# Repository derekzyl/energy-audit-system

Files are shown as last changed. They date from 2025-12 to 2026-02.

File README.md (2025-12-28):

# IoT Enabled  Energy Audit System

A comprehensive, offline energy monitoring solution for real-time power consumption analysis, waste detection, and intelligent energy auditing across multiple wired and wireless loads.

## 🎯 Overview

This system provides a complete energy audit solution without requiring cloud connectivity, internet access, or complex authentication. It consists of a main auditor ESP32 that monitors wired loads and receives data from portable wireless nodes, all accessible through a modern web dashboard.

### Key Features

- **Real-time Energy Monitoring**: Monitor voltage, current, power, energy consumption, and power factor
- **Multi-Device Support**: Simultaneously monitor 2 wired loads (PZEM-004T) and unlimited wireless nodes
- **Intelligent Waste Detection**: Automatic identification of standby waste, usage anomalies, and efficiency issues
- **Wireless Connectivity**: ESP-NOW protocol for low-power, reliable communication without routers
- **Web Dashboard**: Modern, responsive web interface with real-time charts and alerts
- **Portable Nodes**: Battery-powered wireless sensors for flexible deployment
- **Dynamic Device Management**: Automatically discover wireless nodes and manage device names through the web interface
- **Offline Operation**: Complete system works without internet or cloud services
- **Historical Data**: Track power consumption trends over time

## 🏗️ System Architecture

```
┌─────────────────────────┐         ESP-NOW Protocol
│  Wireless Audit Node    │ ────────────────────────▶
│  (SCT-013 Clamp Sensor) │                            │
│  Battery Powered        │                            │
└─────────────────────────┘                            │
                                                       │
                                                       ▼
┌─────────────────────────┐                    ┌─────────────────────┐
│  PZEM-004T Sensor 1     │ ──── UART ────────▶ │                     │
│  (Wired Load 1)         │                    │  Main Auditor ESP32 │
└─────────────────────────┘                    │                     │
                                                │  • WiFi Access Point│
┌─────────────────────────┐                    │  • Web Server      │
│  PZEM-004T Sensor 2     │ ──── UART ────────▶ │  • ESP-NOW Receiver│
│  (Wired Load 2)         │                    │  • Data Storage    │
└─────────────────────────┘                    │  • Waste Detection │
                                                └─────────────────────┘
                                                         │
                                                         ▼
                                                ┌─────────────────────┐
                                                │  Web Dashboard     │
                                                │  (192.168.4.1)     │
                                                │  • Real-time Data  │
                                                │  • Charts & Graphs │
                                                │  • Device Management│
                                                │  • Waste Alerts    │
                                                └─────────────────────┘
```

## 📋 Components

### Main Auditor ESP32
- Acts as WiFi Access Point (SSID: `EnergyAudit-AP`)
- Hosts web dashboard and REST API
- Receives data from wireless nodes via ESP-NOW
- Monitors 2 wired loads via PZEM-004T sensors
- Performs waste detection analysis
- Stores historical data in memory

### Wireless Audit Nodes
- Battery-powered portable sensors
- SCT-013 current clamp sensor
- ESP-NOW transmitter
- Automatic calibration
- Low-power operation

## 🚀 Quick Start

### Prerequisites

- PlatformIO IDE or PlatformIO Core
- ESP32 Development Boards
- Hardware components (see [BOM.md](BOM.md))

### Installation

1. **Clone the repository**
   ```bash
   git clone <repository-url>
   cd energy-audit-system
   ```

2. **Upload Main Auditor Firmware**
   ```bash
   cd firmware
   pio run -t upload
   pio device monitor  # Note the MAC address
   ```

3. **Configure Wireless Node**
   - Update `wireless-audit-device/include/config.h` with main auditor's MAC address
   - Set node ID and sensor parameters

4. **Upload Wireless Node Firmware**
   ```bash
   cd wireless-audit-device
   pio run -t upload
   ```

5. **Access Dashboard**
   - Connect to WiFi: `EnergyAudit-AP` (password: `audit12345`)
   - Open browser: `http://192.168.4.1`

## 📖 Documentation

- **[BOM.md](BOM.md)** - Complete Bill of Materials with part numbers and suppliers
- **[ENERGY_AUDIT_EXPLAINED.md](ENERGY_AUDIT_EXPLAINED.md)** - Detailed explanation of energy audit methodology
- **[SETUP.md](SETUP.md)** - Hardware setup and configuration guide
- **[PROJECT_STRUCTURE.md](PROJECT_STRUCTURE.md)** - Code structure and architecture

## 🔧 Configuration

### Main Auditor
Edit `firmware/include/config.h`:
- WiFi AP credentials
- PZEM sensor pin assignments
- ESP-NOW channel
- Waste detection thresholds

### Wireless Node
Edit `wireless-audit-device/include/config.h`:
- Node ID and name
- Master MAC address
- Sensor calibration values
- Transmission interval

## 💻 API Endpoints

### Device Management
- `GET /api/devices` - List all devices with current readings
- `GET /api/device/:id` - Get specific device details
- `GET /api/devices/:id` - Get device history data
- `POST /api/device/:id/rename` - Rename a device (parameter: `name`)
- `POST /api/device/:id/delete` - Remove a wireless device (wired devices cannot be deleted)

### Dashboard
- `GET /` - Web dashboard interface

## 🎨 Dashboard Features

- **Real-time Monitoring**: Live updates every 2 seconds
- **Device Cards**: Individual cards for each monitored device
- **Power Charts**: Historical power consumption graphs
- **Waste Alerts**: Visual indicators for energy waste
- **Device Management**: 
  - Automatic discovery of wireless nodes when they connect
  - Rename devices with custom names through the web interface
  - Delete wireless devices (wired devices are permanent)
  - Custom names persist during device operation
- **Mobile Responsive**: Works on smartphones and tablets
- **Status Indicators**: Active/inactive device status

## 🔍 Waste Detection

The system automatically detects three types of energy waste:

1. **Standby Waste**: Low current (<0.2A) but still consuming power (>5W)
2. **Usage Anomaly**: Device running continuously 24/7
3. **Efficiency Issue**: Low power factor (<0.7) indicating poor efficiency

## 📊 Data Collection

- **Sampling Rate**: 
  - Wired loads: Every 2 seconds
  - Wireless nodes: Every 5 seconds
- **History Storage**: Last 1000 readings per device (in RAM)
- **Statistics**: Total energy, average power, maximum power, uptime

## 🔌 Hardware Connections

### Main Auditor - PZEM-004T
- **PZEM 1**: RX→GPIO16, TX→GPIO17
- **PZEM 2**: RX→GPIO18, TX→GPIO19
- Connect PZEM in series with loads to measure

### Wireless Node - SCT-013
- Clamp sensor around wire
- Burden resistor (33-62Ω) to GPIO34
- Battery power via 3.3V regulator

See [SETUP.md](SETUP.md) for detailed wiring diagrams.

## 🛠️ Development

### Project Structure
```
energy-audit-system/
├── firmware/              # Main auditor firmware
│   ├── include/          # Header files
│   └── src/              # Source files
├── wireless-audit-device/ # Wireless node firmware
│   ├── include/
│   └── src/
└── docs/                 # Documentation
```

### Building
```bash
# Main auditor
cd firmware
pio run

# Wireless node
cd wireless-audit-device
pio run
```

### Dependencies
- ArduinoJson 6.21.3
- ESPAsyncWebServer 1.2.3
- AsyncTCP 1.1.1

## 🐛 Troubleshooting

### Common Issues

**WiFi AP not starting**
- Check serial monitor for errors
- Verify ESP32 has sufficient power
- Try changing AP channel

**PZEM not reading**
- Verify wiring (RX/TX may be swapped)
- Check PZEM address matches config
- Ensure PZEM is powered (LED should blink)

**ESP-NOW not receiving**
- Verify MAC addresses are correct
- Check both devices on same channel
- Ensure devices are powered on

**Wireless node inaccurate readings**
- Recalibrate sensor (power off, remove load, power on)
- Verify burden resistor value
- Check SCT-013 clamp is secure

See [SETUP.md](SETUP.md) for detailed troubleshooting.

## 📈 Future Enhancements

- [ ] Deep sleep mode for wireless nodes
- [ ] Voltage sensor for wireless nodes
- [ ] SPIFFS/SD card data logging
- [ ] Energy cost calculations
- [ ] CSV data export
- [ ] Mobile app interface
- [ ] Multi-language support
- [ ] Advanced analytics and reporting

## 📝 License

This project is provided as-is for educational and development purposes.

## 🤝 Contributing

Contributions are welcome! Please feel free to submit pull requests or open issues for bugs and feature requests.

## 📧 Support

For questions, issues, or contributions, please open an issue on the repository.

---

**Version**: 1.0.0  
**Last Updated**: 2025  
**Platform**: ESP32 (Arduino Framework)

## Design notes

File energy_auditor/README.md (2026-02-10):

# energy_auditor

A new Flutter project.

## Getting Started

This project is a starting point for a Flutter application.

A few resources to get you started if this is your first Flutter project:

- [Lab: Write your first Flutter app](https://docs.flutter.dev/get-started/codelab)
- [Cookbook: Useful Flutter samples](https://docs.flutter.dev/cookbook)

For help getting started with Flutter development, view the
[online documentation](https://docs.flutter.dev/), which offers tutorials,
samples, guidance on mobile development, and a full API reference.

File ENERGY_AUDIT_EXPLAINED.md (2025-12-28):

# Energy Audit System - How It Works

A comprehensive explanation of the energy audit methodology, measurement techniques, and intelligent waste detection algorithms.

## 📊 Overview

This system performs real-time energy auditing by measuring electrical parameters (voltage, current, power) and analyzing consumption patterns to identify energy waste and optimization opportunities.

## 🔌 Measurement Methods

### 1. Wired Loads (PZEM-004T)

**How It Works:**
- PZEM-004T is an inline energy meter that connects in series with the load
- Uses a current transformer (CT) to measure current non-invasively
- Directly measures voltage, current, power, energy, frequency, and power factor
- Communicates via Modbus RTU protocol over UART

**Advantages:**
- High accuracy (±1%)
- Direct voltage measurement (no assumptions)
- Real power factor measurement
- Energy accumulation (kWh)
- Frequency measurement

**Limitations:**
- Requires physical connection to load
- Not portable
- Installation requires electrical work

**Measurement Parameters:**
```
Voltage (V):     80-260V AC (direct measurement)
Current (A):     0-100A (via CT)
Power (W):       0-22.9kW (calculated: V × I × PF)
Energy (kWh):    Accumulated over time
Frequency (Hz):  50-60Hz
Power Factor:    0.0-1.0 (cosine of phase angle)
```

### 2. Wireless Nodes (SCT-013)

**How It Works:**
- SCT-013 is a non-invasive current transformer (clamp sensor)
- Clamps around a single wire (not the entire cable)
- Outputs current proportional to line current (100A:50mA ratio)
- Burden resistor converts current to voltage for ADC reading
- ESP32 ADC samples the waveform and calculates RMS current

**Advantages:**
- Non-invasive installation (no wiring changes)
- Portable and battery-powered
- Easy to move between loads
- Safe (no direct electrical connection)

**Limitations:**
- Only measures current (voltage assumed)
- Power factor estimated (not measured)
- Less accurate than PZEM (±3% vs ±1%)
- Requires calibration

**Measurement Process:**

```
1. Clamp SCT-013 around wire
   ↓
2. AC current induces current in sensor (proportional)
   ↓
3. Burden resistor converts to voltage: V = I_sensor × R_burden
   ↓
4. ESP32 ADC samples waveform at 10kHz
   ↓
5. Calculate RMS current: I_RMS = √(Σ(I²)/N)
   ↓
6. Estimate power: P = I_RMS × V_assumed × PF_estimated
```

**Power Calculation:**
```
Power (W) = Current (A) × Voltage (V) × Power Factor

Where:
- Current: Measured RMS value
- Voltage: Assumed 230V (configurable)
- Power Factor: Estimated based on load characteristics
  - Small loads (<0.5A): PF ≈ 0.75
  - Medium loads (0.5-2A): PF ≈ 0.85
  - Large loads (>2A): PF ≈ 0.90
```

## 🧮 Electrical Calculations

### RMS Current Calculation

For AC circuits, we need Root Mean Square (RMS) current, not peak current:

```
I_RMS = √(1/T × ∫[i(t)]² dt)

Where:
- T = period (20ms for 50Hz)
- i(t) = instantaneous current

In practice (discrete sampling):
I_RMS = √(Σ(I_sample²) / N)

Where N = number of samples
```

### Power Calculations

**Real Power (W):**
```
P = V_RMS × I_RMS × cos(φ)

Where:
- V_RMS = RMS voltage
- I_RMS = RMS current  
- φ = phase angle between voltage and current
- cos(φ) = power factor
```

**Apparent Power (VA):**
```
S = V_RMS × I_RMS
```

**Reactive Power (VAR):**
```
Q = V_RMS × I_RMS × sin(φ)
```

**Power Factor:**
```
PF = P / S = cos(φ)
```

### Energy Calculation

Energy is power integrated over time:

```
E = ∫ P(t) dt

In discrete form:
E = Σ(P_i × Δt_i)

Where:
- P_i = power at sample i
- Δt_i = time interval between samples
```

The system accumulates energy in kWh:
```
E_kWh = E_Joules / 3,600,000
```

## 🔍 Waste Detection Algorithms

### 1. Standby Waste Detection

**Definition:** Device consuming power while in standby/low-power mode.

**Detection Logic:**
```cpp
if (current < 0.2A && power > 5W) {
    standbyWaste = true;
}
```

**Why This Works:**
- Low current (<0.2A) suggests device is "off" or in standby
- But power >5W indicates it's still consuming energy
- This is wasteful - device should consume <1W in standby

**Examples:**
- TV on standby: 0.15A @ 230V = 34.5W (wasteful!)
- Phone charger (no phone): 0.05A @ 230V = 11.5W (wasteful!)
- LED bulb: 0.08A @ 230V = 18.4W (normal, not waste)

**Thresholds:**
- Current threshold: 0.2A (configurable)
- Power threshold: 5W (configurable)

### 2. Usage Anomaly Detection

**Definition:** Device running continuously 24/7, indicating potential waste.

**Detection Logic:**
```cpp
// Analyze last 100 readings
int alwaysOnCount = 0;
for (int i = 0; i < 100; i++) {
    if (history[i].power > 1.0W) {
        alwaysOnCount++;
    }
}

// If 95%+ of readings show consumption
if (alwaysOnCount >= 95) {
    usageAnomaly = true;
}
```

**Why This Works:**
- Most devices should have periods of zero/low consumption
- Continuous consumption suggests:
  - Device left on unnecessarily
  - Faulty device (always drawing power)
  - Critical system (acceptable, but flagged for review)

**Examples:**
- Refrigerator: Always on (normal, but flagged)
- Server/Computer: Always on (may be unnecessary)
- Security system: Always on (normal)
- Light left on: Always on (wasteful!)

**Analysis Window:**
- Checks last 100 readings
- At 5-second intervals = ~8.3 minutes of data
- Can be extended for longer-term analysis

### 3. Efficiency Issue Detection

**Definition:** Low power factor indicates poor electrical efficiency.

**Detection Logic:**
```cpp
if (powerFactor > 0.0 && powerFactor < 0.7) {
    efficiencyIssue = true;
}
```

**Why This Works:**
- Power factor < 1.0 means device draws more current than needed
- Low PF (<0.7) indicates:
  - Reactive loads (motors, transformers)
  - Poor power quality
  - Inefficient power supply
  - Need for power factor correction

**Power Factor Ranges:**
- **Excellent**: 0.95 - 1.0 (resistive loads, modern electronics)
- **Good**: 0.85 - 0.95 (most appliances)
- **Fair**: 0.70 - 0.85 (motors, some electronics)
- **Poor**: < 0.70 (inductive loads, old equipment)

**Examples:**
- LED bulb: PF ≈ 0.95 (good)
- Laptop: PF ≈ 0.90 (good)
- Refrigerator: PF ≈ 0.65 (poor, needs correction)
- Old fluorescent light: PF ≈ 0.50 (very poor)

**Impact:**
- Low PF increases current draw
- Higher current = more losses in wiring
- Utility may charge for reactive power
- Reduces overall system efficiency

## 📈 Data Analysis and Statistics

### Real-time Metrics

**Current Reading:**
- Latest voltage, current, power, energy, frequency, PF
- Timestamp of measurement
- Device status (active/inactive)

**Historical Data:**
- Circular buffer of last 1000 readings
- Stored in RAM (fast access)
- Used for trend analysis

### Calculated Statistics

**Total Energy:**
```
E_total = Σ(P_i × Δt_i) / 3,600,000 kWh
```

**Average Power:**
```
P_avg = (Σ P_i) / N
```

**Maximum Power:**
```
P_max = max(P_i)
```

**Uptime:**
```
Uptime = (last_seen - first_seen) seconds
```

## 🔄 System Workflow

### Main Auditor Operation

```
1. Initialize WiFi AP
   ↓
2. Start web server
   ↓
3. Initialize ESP-NOW receiver
   ↓
4. Initialize PZEM sensors
   ↓
5. Main Loop:
   ├─ Read PZEM sensors (every 2s)
   ├─ Receive ESP-NOW packets (asynchronous)
   ├─ Update device data
   ├─ Run waste detection (every 60s)
   └─ Serve web requests
```

### Wireless Node Operation

```
1. Initialize WiFi (for ESP-NOW)
   ↓
2. Calibrate current sensor (find DC offset)
   ↓
3. Initialize ESP-NOW transmitter
   ↓
4. Main Loop:
   ├─ Sample current waveform (100 samples)
   ├─ Calculate RMS current
   ├─ Estimate power
   ├─ Create JSON packet
   └─ Transmit via ESP-NOW (every 5s)
```

## 🎯 Accuracy and Calibration

### PZEM-004T Accuracy
- **Voltage**: ±1% (factory calibrated)
- **Current**: ±1% (via CT)
- **Power**: ±1% (calculated)
- **Energy**: ±1% (accumulated)

### SCT-013 Accuracy
- **Current**: ±3% (after calibration)
- **Power**: ±5-10% (due to assumed voltage and PF)

### Calibration Process

**Wireless Node:**
1. Power on with no load
2. System measures DC offset
3. Offset subtracted from all readings
4. Burden resistor value verified
5. Current ratio verified

**PZEM:**
- Factory calibrated
- Verify with known load if needed

## 📊 Data Interpretation

### Understanding Readings

**Normal Operation:**
- Current varies with load
- Power factor 0.85-0.95
- Periodic zero consumption

**Standby Mode:**
- Current < 0.2A
- Power < 5W (ideal) or > 5W (wasteful)
- Power factor may be low

**Fault Conditions:**
- Sudden power spikes
- Erratic readings
- Zero readings (connection issue)

### Energy Waste Indicators

**High Priority:**
- Standby waste detected
- Usage anomaly (24/7 operation)
- Low power factor (<0.7)

**Medium Priority:**
- Continuous low consumption
- High idle power

**Low Priority:**
- Occasional waste
- Acceptable 24/7 operation (refrigerator, etc.)

## 🔧 Optimization Recommendations

Based on waste detection, the system can suggest:

1. **Standby Waste**: Unplug device or use smart switch
2. **Usage Anomaly**: Review if device needs to run 24/7
3. **Efficiency Issue**: Consider power factor correction capacitor

## 📚 Technical References

### Standards
- **IEC 61000-4-30**: Power quality measurement
- **IEEE 1459**: Power definitions
- **IEC 62053**: Energy metering

### Formulas
- **RMS Calculation**: I_RMS = √(1/T × ∫i²dt)
- **Power Factor**: PF = P / (V × I)
- **Energy**: E = ∫P dt

### Typical Power Factors
- Resistive loads: 1.0
- LED lights: 0.95-0.99
- Computers: 0.85-0.95
- Motors: 0.60-0.85
- Fluorescent lights: 0.50-0.90

---

**Last Updated**: 2025  
**Version**: 1.0.0

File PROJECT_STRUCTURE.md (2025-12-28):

# Project Structure

## Directory Layout

```
energy-audit-system/
├── firmware/                    # Main Auditor ESP32 Firmware
│   ├── include/
│   │   ├── config.h            # Configuration (WiFi, PZEM pins, thresholds)
│   │   ├── device_data.h       # Data structures for devices and readings
│   │   ├── pzem_sensor.h       # PZEM-004T sensor interface
│   │   └── waste_detector.h    # Waste detection algorithms
│   ├── src/
│   │   ├── main.cpp            # Main firmware (WiFi AP, Web server, ESP-NOW)
│   │   ├── pzem_sensor.cpp     # PZEM sensor implementation
│   │   └── waste_detector.cpp  # Waste detection implementation
│   ├── platformio.ini          # PlatformIO configuration
│   └── ...
│
├── wireless-audit-device/       # Wireless Node Firmware
│   ├── include/
│   │   ├── config.h            # Node configuration (sensor pins, ESP-NOW)
│   │   └── current_sensor.h    # SCT-013 current sensor interface
│   ├── src/
│   │   ├── main.cpp            # Main node firmware (ESP-NOW transmitter)
│   │   └── current_sensor.cpp  # Current sensor implementation
│   ├── platformio.ini          # PlatformIO configuration
│   └── ...
│
├── readme.md                    # Project overview and architecture
├── SETUP.md                     # Hardware setup and configuration guide
└── PROJECT_STRUCTURE.md         # This file
```

## Key Components

### Main Auditor (`firmware/`)

**Core Features:**
- WiFi Access Point mode (SSID: `EnergyAudit-AP`)
- Web server with real-time dashboard
- ESP-NOW receiver for wireless nodes
- 2x PZEM-004T sensor interfaces (wired loads)
- REST API endpoints
- Waste detection algorithms
- Data storage and history tracking

**Main Files:**
- `main.cpp`: Orchestrates WiFi AP, web server, ESP-NOW, and PZEM sensors
- `pzem_sensor.cpp`: Modbus RTU communication with PZEM-004T
- `waste_detector.cpp`: Analyzes devices for standby waste, anomalies, efficiency issues

**API Endpoints:**
- `GET /` - Web dashboard (HTML)
- `GET /api/devices` - List all devices with current readings
- `GET /api/device/:id` - Get specific device details
- `GET /api/devices/:id` - Get device history data

### Wireless Node (`wireless-audit-device/`)

**Core Features:**
- SCT-013 current clamp sensor reading
- RMS current calculation
- Power estimation (Current × Voltage × PF)
- ESP-NOW transmitter to main auditor
- Battery-powered operation
- Auto-calibration on startup

**Main Files:**
- `main.cpp`: ESP-NOW transmission, sensor reading loop
- `current_sensor.cpp`: ADC sampling, RMS calculation, power factor estimation

## Data Flow

```
Wireless Node                    Main Auditor                    Web Dashboard
     │                                │                                │
     │ 1. Sample SCT-013              │                                │
     │ 2. Calculate RMS Current        │                                │
     │ 3. Estimate Power               │                                │
     │                                │                                │
     │ ──── ESP-NOW ─────────────────▶│                                │
     │                                │ 4. Parse JSON packet            │
     │                                │ 5. Update device data           │
     │                                │ 6. Run waste detection          │
     │                                │                                │
     │                                │ ──── HTTP Request ────────────▶│
     │                                │                                │ 7. Display data
     │                                │                                │ 8. Show alerts
     │                                │                                │ 9. Update charts
     │                                │                                │
     │                                │                                │
PZEM Sensors ──── UART ──────────────▶│                                │
     │                                │ Read voltage, current, power    │
     │                                │ Update device data              │
     │                                │                                │
```

## Configuration Files

### `firmware/include/config.h`
- WiFi AP credentials
- PZEM pin assignments
- ESP-NOW channel
- Waste detection thresholds
- Device IDs

### `wireless-audit-device/include/config.h`
- Node ID and name
- SCT-013 sensor configuration
- Burden resistor value
- ESP-NOW master MAC address
- Transmission interval

## Waste Detection

The system detects three types of energy waste:

1. **Standby Waste**: Current < 0.2A but power > 5W
   - Indicates device consuming power in standby mode

2. **Usage Anomaly**: Device running 24/7
   - Detected by analyzing history (95%+ of readings show consumption)

3. **Efficiency Issue**: Power factor < 0.7
   - Low power factor indicates poor efficiency

## Data Structures

### `DeviceReading`
- voltage, current, power, energy, frequency, powerFactor
- timestamp

### `DeviceInfo`
- Device identification (id, name, type)
- Current reading
- History buffer (circular)
- Statistics (total energy, avg/max power)
- Waste detection flags
- Status (active/inactive, last seen)

## Dependencies

### Main Auditor
- `ArduinoJson` - JSON parsing/generation
- `ESPAsyncWebServer` - Async web server
- `AsyncTCP` - TCP library for async server

### Wireless Node
- `ArduinoJson` - JSON packet creation

## Build & Upload

### Main Auditor
```bash
cd firmware
pio run -t upload
pio device monitor  # View serial output
```

### Wireless Node
```bash
cd wireless-audit-device
pio run -t upload
pio device monitor  # View serial output
```

## Testing

1. Upload main auditor firmware
2. Note MAC address from serial monitor
3. Update wireless node config with MAC address
4. Upload wireless node firmware
5. Connect to WiFi AP: `EnergyAudit-AP`
6. Open browser: `http://192.168.4.1`
7. Verify devices appear in dashboard

## Notes

- PZEM sensors use Modbus RTU over UART (9600 baud)
- ESP-NOW uses channel 1 by default
- Web dashboard auto-refreshes every 2 seconds
- History is stored in RAM (circular buffer, max 1000 entries)
- Wireless node transmits every 5 seconds
- PZEM sensors are read every 2 seconds

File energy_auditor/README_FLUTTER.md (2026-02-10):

# Energy Auditor Mobile App

## Overview
Flutter application for monitoring energy usage and receiving waste alerts.

## Features
-   Real-time Dashboard (Watts, Amps, Temp, Lux).
-   Active Waste Alerts (Overcooling, Lights on, etc.).
-   Historical Analytics Charts.
-   Device Configuration.

## Setup
1.  Navigate to `energy_auditor/`.
2.  Get dependencies: `flutter pub get`.
3.  Run:
    ```bash
    flutter run
    ```

## Configuration
-   On first launch, go to **Settings** icon.
-   Enter Backend URL: `http://YOUR_PC_IP:8000`.
-   Enter Device ID: `ESP32_...` (matches firmware ID).

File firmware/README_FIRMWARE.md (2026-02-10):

# ESP32 Firmware for Energy Audit System

## Overview
This firmware runs on the ESP32 and performs:
-   RMS Current reading from 2x ACS712 sensors.
-   Environmental sensing (DHT22, LDR).
-   Dual WiFi Mode (AP for config, Station for normal op).
-   Local Web Dashboard.
-   JSON data push to FastAPI Backend.

## Hardware Config
-   **ACS712 1**: GPIO 34
-   **ACS712 2**: GPIO 35
-   **LDR**: GPIO 32
-   **DHT22**: GPIO 4

## Setup
1.  Open `firmware/` in VS Code with PlatformIO.
2.  Connect ESP32 via USB.
3.  Click **Upload**.
4.  Monitor Serial Output (115200 baud).

## usage
-   **First Run**: Connect to WiFi AP `EnergyMonitor_Setup` (Pass: `energy123`).
-   Go to `http://192.168.4.1/config`.
-   Enter your Backend URL (e.g., `http://YOUR_PC_IP:8000`).
-   Save & Reboot.

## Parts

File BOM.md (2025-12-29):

# Bill of Materials (BOM)

Complete parts list for the IoT Enabled  Energy Audit System.

## Main Auditor ESP32

| Part | Quantity | Description | Part Number/Supplier |
|---|---|---|---|
| ESP32 Development Board | 1 | ESP32-WROOM-32 or ESP32-DevKitC | ESP32-DevKitC-32 |
| PZEM-004T Energy Meter | 2 | AC Energy Monitor Module | PZEM-004T |
| USB Power Supply | 1 | 5V 2A USB Power Adapter | Generic 5V/2A USB |
| USB Cable (Type-A to Micro-B) | 1 | For power and programming | Generic USB cable |
| Jumper Wires | 8 | Male-to-Male, 20cm | Generic jumper wires |
| Breadboard (optional) | 1 | For prototyping connections | Half-size breadboard |

### PZEM-004T Specifications
- **Voltage Range**: 80-260V AC
- **Current Range**: 0-100A (via CT)
- **Power Range**: 0-22.9kW
- **Communication**: Modbus RTU over UART (9600 baud)
- **Accuracy**: ±1%
- **Isolation**: Optically isolated

## Wireless Audit Node

| Part | Quantity | Description | Part Number/Supplier |
|---|---|---|---|
| ESP32 Development Board | 1 | ESP32-WROOM-32 or ESP32-DevKitC | ESP32-DevKitC-32 |
| SCT-013 Current Sensor | 1 | 100A/50mA AC Current Transformer | SCT-013-000 |
| Burden Resistor | 1 | 33Ω - 62Ω, 1W | 47Ω 1W resistor |
| 3.3V Linear Regulator | 1 | AMS1117-3.3 or LM1117-3.3 | AMS1117-3.3 |
| Li-ion Battery | 1 | 18650 3.7V 2000-3000mAh | 18650 Li-ion |
| Battery Holder | 1 | 18650 Battery Holder | 18650 holder |
| Capacitor (optional) | 1 | 10nF ceramic capacitor | 10nF 50V |
| Resistor (voltage divider) | 2 | 10kΩ for battery monitoring | 10kΩ 1/4W |
| Enclosure (optional) | 1 | Project box for protection | Small project box |

### SCT-013 Specifications
- **Current Range**: 0-100A AC
- **Output**: 0-50mA (proportional to input current)
- **Ratio**: 100A:50mA (2000:1)
- **Frequency**: 50-60Hz
- **Accuracy**: ±3%
- **Opening**: 13mm diameter

### Burden Resistor Selection
- **Recommended**: 47Ω (good balance)
- **Range**: 33Ω - 62Ω
- **Power Rating**: 1W minimum
- **Formula**: V = I × R (where I is sensor output current)

## Optional Components

| Part | Quantity | Description | Use Case |
|---|---|---|---|
| SD Card Module | 1 | MicroSD card reader | Data logging |
| MicroSD Card | 1 | 8GB or larger | Storage |
| OLED Display | 1 | 0.96" I2C OLED | Local display |
| Voltage Sensor | 1 | ZMPT101B AC Voltage | Better accuracy for wireless nodes |
| Relay Module | 1 | 1-channel relay | Load control |
| Enclosure (Main) | 1 | Larger project box | Main auditor protection |

## Tools Required

| Tool | Purpose |
|---|---|
| Soldering Iron | For permanent connections |
| Multimeter | Testing and verification |
| Wire Strippers | Preparing wires |
| Breadboard | Prototyping (optional) |
| USB to Serial Adapter | Programming ESP32 (if not using USB) |

## Total System Cost

Costs vary by supplier and region. Typical ranges:
- **Main Auditor**: $25-40
- **Wireless Node**: $20-35 per node
- **Total (1 Main + 1 Node)**: $45-75
- **Total (1 Main + 2 Nodes)**: $65-110

## Notes

### Power Consumption
- **Main Auditor**: ~200-300mA @ 5V (1-1.5W)
- **Wireless Node**: ~80-150mA @ 3.3V (0.26-0.5W) when active
- **Wireless Node (Sleep)**: <10mA @ 3.3V (future enhancement)

### Battery Life Estimation (Wireless Node)
- **3000mAh Battery**: ~20-37 hours continuous operation
- **With Deep Sleep**: 30+ days (future enhancement)

### Safety Considerations
- **AC Voltage**: Always exercise caution when working with AC power
- **Isolation**: PZEM-004T provides optical isolation
- **SCT-013**: Non-invasive, safe to use
- **Battery**: Use protected Li-ion cells, handle with care

---

**Last Updated**: 2025

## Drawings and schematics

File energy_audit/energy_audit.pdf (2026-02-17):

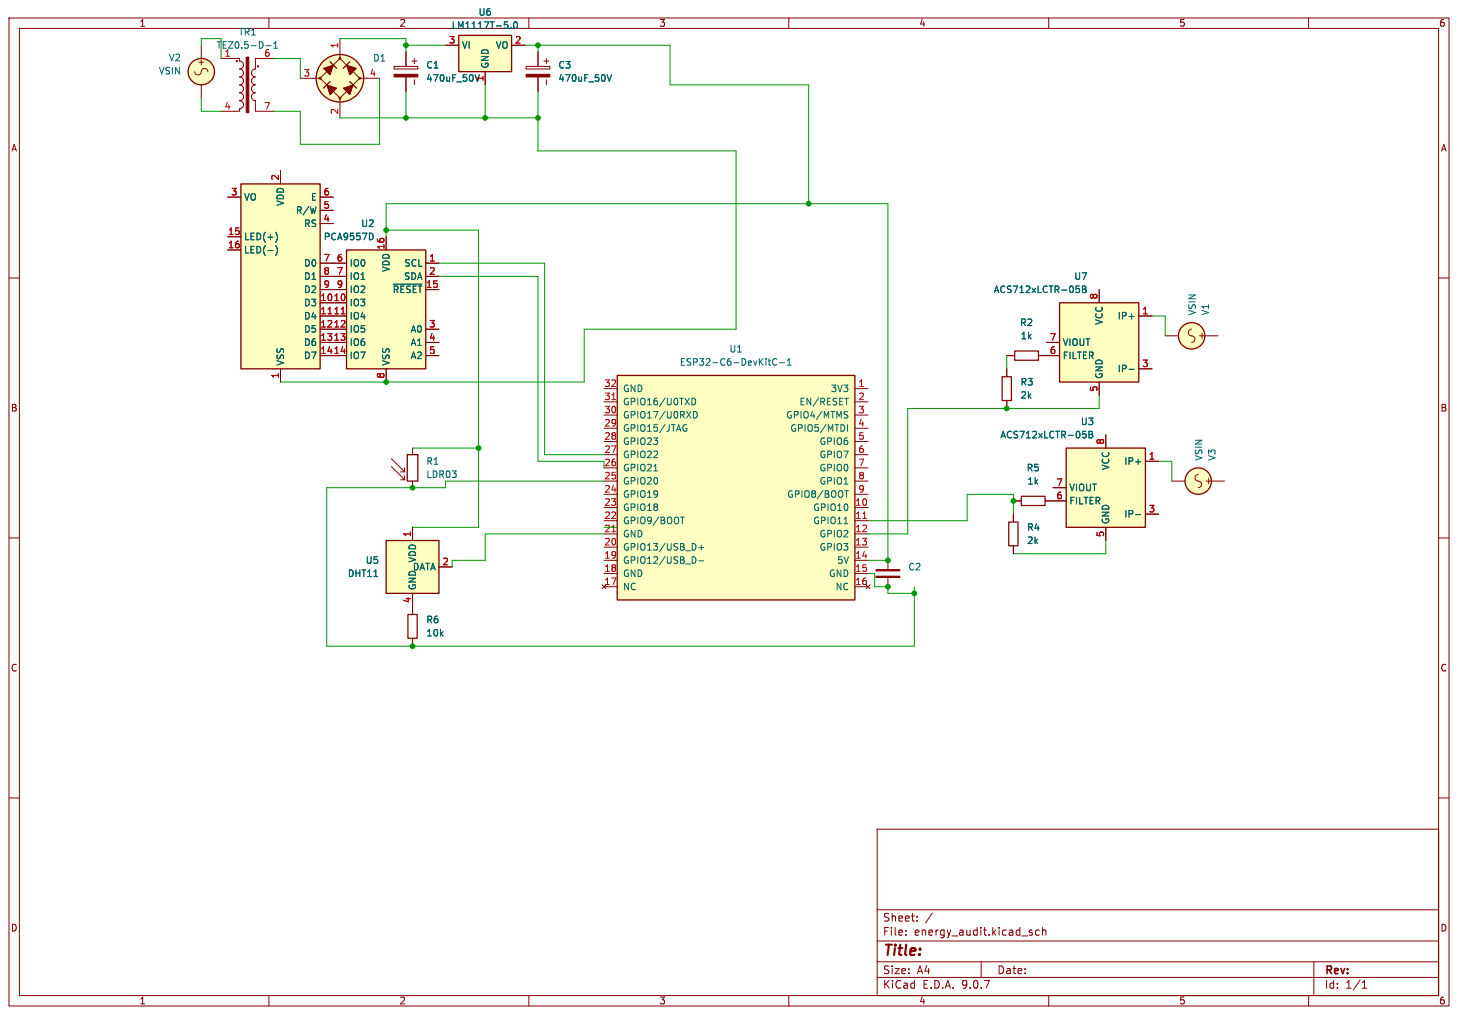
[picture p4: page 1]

Id: 1/1 Title: File: energy_audit.kicad_sch Sheet: /

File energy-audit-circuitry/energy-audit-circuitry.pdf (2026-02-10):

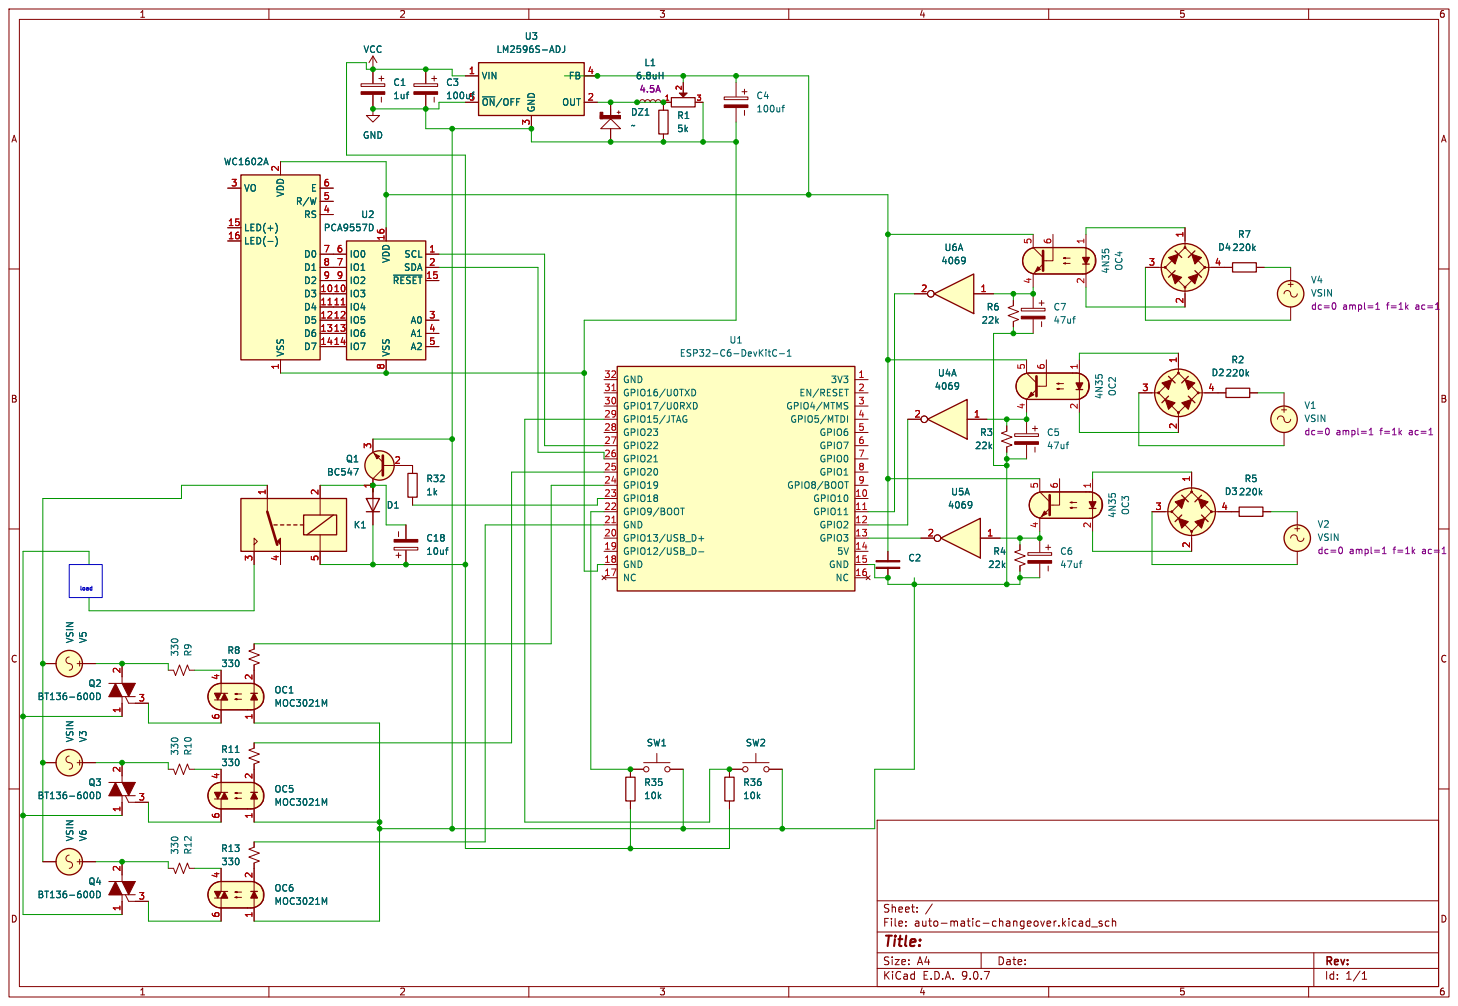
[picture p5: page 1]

6 R/W 5 RS 4 D0 7 D1 8 D2 9 D3 10 D4 11 D5 12 D6 13 D7 14 VDD
SCL 1 SDA 2 ~{RESET} 15 A0 3 A1 4 A2 5 VDD 16 VSS

3 FB 4 OUT 2 GND
1uf GND

Id: 1/1 Title: File: auto-matic-changeover.kicad_sch Sheet: / + VSIN V6

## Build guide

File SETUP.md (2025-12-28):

# Energy Audit System - Setup Guide

## System Overview

This IoT-enabled energy audit system consists of:
- **Main Auditor ESP32**: Monitors 2 wired loads (via PZEM-004T) and receives data from wireless nodes
- **Wireless Audit Node**: Battery-powered node with SCT-013 clamp sensor

## Hardware Requirements

### Main Auditor ESP32
- ESP32 Development Board
- 2x PZEM-004T Energy Meters (for wired loads)
- 5V USB Power Supply
- Jumper wires for PZEM connections

### Wireless Audit Node
- ESP32 Development Board
- SCT-013 100A/50mA Current Clamp Sensor
- Burden Resistor (33Ω - 62Ω recommended)
- 3.3V Regulator + Li-ion Battery (for portable operation)
- Voltage divider for battery monitoring (optional)

## Hardware Connections

### Main Auditor - PZEM-004T Connections

**PZEM 1:**
- VCC → 5V
- GND → GND
- RX → GPIO 16 (configured in `config.h`)
- TX → GPIO 17 (configured in `config.h`)

**PZEM 2:**
- VCC → 5V
- GND → GND
- RX → GPIO 18 (configured in `config.h`)
- TX → GPIO 19 (configured in `config.h`)

**Note:** PZEM-004T should be connected in series with the load you want to measure.

### Wireless Node - SCT-013 Connections

**SCT-013 Sensor:**
- Clamp around the wire you want to measure
- Output wires → Burden Resistor (33Ω - 62Ω)
- One end of burden resistor → GPIO 34 (ADC1_CH6)
- Other end → GND
- Add a small capacitor (10nF) across the burden resistor for noise filtering (optional)

**Power:**
- Connect 3.3V regulator output to ESP32 3.3V
- Connect battery to regulator input
- Connect GND

## Software Setup

### 1. Install PlatformIO

Install PlatformIO IDE or PlatformIO Core:
- VS Code Extension: [PlatformIO IDE](https://platformio.org/install/ide?install=vscode)
- Or use PlatformIO Core: `pip install platformio`

### 2. Configure Main Auditor

1. Open `firmware/platformio.ini` - already configured
2. Update `firmware/include/config.h` if needed:
   - Adjust PZEM pin numbers if using different GPIOs
   - Change WiFi AP SSID/password if desired
3. Upload firmware:
   ```bash
   cd firmware
   pio run -t upload
   ```

### 3. Configure Wireless Node

1. **Important:** Get the Main Auditor's MAC address:
   - Upload main auditor firmware first
   - Open serial monitor (115200 baud)
   - Note the MAC address printed at startup

2. Update `wireless-audit-device/include/config.h`:
   - Set `MASTER_MAC_ADDR` to the main auditor's MAC address
   - Or use broadcast mode: `{0xFF, 0xFF, 0xFF, 0xFF, 0xFF, 0xFF}`
   - Adjust `SCT013_BURDEN_RESISTOR` value to match your resistor
   - Adjust `SCT013_CURRENT_RATIO` if using different SCT-013 model

3. Upload firmware:
   ```bash
   cd wireless-audit-device
   pio run -t upload
   ```

### 4. Calibration

**Wireless Node:**
- The sensor auto-calibrates on startup (finds DC offset)
- For better accuracy, ensure no load is connected during first boot
- Adjust burden resistor value in config if readings are off

**PZEM Sensors:**
- PZEM-004T is factory calibrated
- Verify readings with a known load

## Usage

### Accessing the Dashboard

1. Power on the Main Auditor ESP32
2. Connect to WiFi network: `EnergyAudit-AP` (password: `audit12345`)
3. Open browser and go to: `http://192.168.4.1` (or check serial monitor for actual IP)
4. Dashboard will auto-refresh every 2 seconds

### Dashboard Features

- **Real-time Monitoring**: See current, voltage, power, and power factor for all devices
- **Waste Detection Alerts**:
  - ⚠️ Standby waste: Low current but still consuming power
  - ⚠️ Usage anomaly: Device running 24/7
  - ⚠️ Efficiency issue: Low power factor detected
- **Power History Chart**: Visual graph of power consumption over time
- **Device Status**: Active/Inactive indicators

### API Endpoints

- `GET /api/devices` - Get all devices and current readings
- `GET /api/device/:id` - Get specific device details
- `GET /api/devices/:id` - Get device history data

## Troubleshooting

### Main Auditor Issues

**WiFi AP not starting:**
- Check serial monitor for error messages
- Try changing AP channel in config.h

**PZEM not reading:**
- Verify wiring (RX/TX might be swapped)
- Check PZEM address matches config
- Ensure PZEM is powered (LED should blink)

**ESP-NOW not receiving:**
- Verify both devices are on same channel
- Check MAC address configuration in wireless node

### Wireless Node Issues

**No data received:**
- Verify MAC address is correct
- Check ESP-NOW channel matches main auditor
- Ensure both devices are powered on

**Inaccurate current readings:**
- Recalibrate by powering off, removing load, powering on
- Check burden resistor value
- Verify SCT-013 is properly clamped (not loose)

**Battery draining fast:**
- Reduce `TRANSMIT_INTERVAL_MS` (but increases battery usage)
- Consider deep sleep mode (not implemented yet)

## Power Calculations

### Wireless Node
- Power = Current × 230V × Power Factor (0.85 default)
- Voltage is assumed (230V for most regions, adjust in config.h)

### Wired Loads (PZEM)
- All values directly measured by PZEM-004T
- More accurate than wireless node estimates

## Future Enhancements

- [ ] Deep sleep mode for wireless nodes
- [ ] Voltage sensor for wireless nodes (improve accuracy)
- [ ] Data logging to SPIFFS/SD card
- [ ] Mobile app interface
- [ ] Energy cost calculations
- [ ] Export data to CSV

## License

This project is provided as-is for educational and development purposes.

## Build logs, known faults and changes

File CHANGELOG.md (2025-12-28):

# Changelog

## [1.0.0] - 2025

### Added
- **Main Auditor ESP32 Firmware**
  - WiFi Access Point mode
  - Web server with responsive dashboard
  - ESP-NOW receiver for wireless nodes
  - 2x PZEM-004T sensor support (wired loads)
  - REST API endpoints
  - Waste detection algorithms
  - Historical data storage
  - **Dynamic device management**
    - Automatic wireless node discovery
    - Device renaming via web interface
    - Device deletion (wireless nodes only)
    - Custom device names with fallback to defaults

- **Wireless Node Firmware**
  - SCT-013 current sensor support
  - RMS current calculation
  - Power estimation
  - ESP-NOW transmitter
  - Auto-calibration
  - Battery-friendly operation

- **Web Dashboard**
  - Real-time device monitoring
  - Power consumption charts (Chart.js)
  - Waste detection alerts
  - Device management UI
  - Mobile-responsive design
  - Auto-refresh every 2 seconds

- **Documentation**
  - Professional README.md
  - Complete BOM.md (Bill of Materials)
  - ENERGY_AUDIT_EXPLAINED.md (technical details)
  - SETUP.md (hardware setup guide)
  - PROJECT_STRUCTURE.md (code architecture)

### Features

#### Dynamic Device Management
- Wireless nodes are automatically added when they first transmit data
- Devices can be renamed through the web dashboard
- Custom names are stored and displayed instead of default names
- Wireless devices can be deleted (wired devices are permanent)
- Device names are shown in charts and throughout the UI

#### Waste Detection
- Standby waste detection (low current, high power)
- Usage anomaly detection (24/7 operation)
- Efficiency issue detection (low power factor)

#### Data Collection
- Real-time readings every 2 seconds (wired) / 5 seconds (wireless)
- Historical data storage (last 1000 readings per device)
- Statistics: total energy, average power, maximum power

### Technical Details

- **Platform**: ESP32 (Arduino Framework)
- **Communication**: ESP-NOW (wireless), UART/Modbus (wired)
- **Web Framework**: ESPAsyncWebServer
- **Data Format**: JSON
- **Storage**: RAM (circular buffers)

### Known Limitations

- Device names stored in RAM (lost on reboot)
- Maximum 10 devices supported
- History limited to 1000 readings per device
- No persistent storage (SPIFFS/SD card not implemented yet)

### Future Enhancements

- [ ] Persistent device name storage (SPIFFS)
- [ ] Deep sleep mode for wireless nodes
- [ ] Voltage sensor for wireless nodes
- [ ] SD card data logging
- [ ] Energy cost calculations
- [ ] CSV export
- [ ] Mobile app
- [ ] Multi-language support

---

**Version**: 1.0.0  
**Release Date**: 2025

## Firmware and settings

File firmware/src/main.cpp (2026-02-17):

#include <Arduino.h>
#include <WiFi.h>
#include <WiFiClientSecure.h>
#include <AsyncTCP.h>
#include <ESPAsyncWebServer.h>
#include <ArduinoJson.h>
#include <DHT.h>
#include <Preferences.h>
#include <HTTPClient.h>
#include <LiquidCrystal_I2C.h>

// --- Configuration ---
#define ACS712_SENSOR_1_PIN 34
#define ACS712_SENSOR_2_PIN 35
#define LDR_PIN 32
#define DHT_PIN 4

#define ACS712_SENSITIVITY 0.066 // 66mV/A for 30A module
#define ADC_VOLTAGE_REF 3.3
#define ADC_RESOLUTION 4095.0
#define VOLTAGE_DIVIDER_RATIO 1.0 // Set to 1.0 if sensor connected directly (no divider)

#define DEFAULT_VOLTAGE 220.0
#define DEFAULT_PF 0.95

// --- Globals ---
AsyncWebServer server(80);
DHT dht(DHT_PIN, DHT22);
Preferences preferences;
LiquidCrystal_I2C lcd(0x27, 16, 2); // Set the LCD address to 0x27 for a 16 chars and 2 line display

// Sensor Data
float current1 = 0.0;
float watts1 = 0.0;
float current2 = 0.0;
float watts2 = 0.0;
float temperature = 0.0;
float humidity = 0.0;
int lightRaw = 0;
int lightLux = 0; // Approximate

// Calibration
float zeroOffset1 = 2.5; // Default 2.5V (will be calibrated)
float zeroOffset2 = 2.5;

// WiFi & Backend
String backendUrl = "https://xenophobic-netta-cybergenii-1584fde7.koyeb.app"; // Default backend URL
String deviceId = "ESP32_ENERGY_MONITOR"; // Constant ID for App consistency

// Timers
unsigned long lastRead = 0;
unsigned long lastSend = 0;

// --- Function Prototypes ---
void initWiFi();
void initWebServer();
float readACS712(int pin, float zeroOffset);
void calibrateSensors();
void sendToBackend();
String getDashboardJSON();

// --- Setup ---
void setup() {
  Serial.begin(115200);
  
  // Set ADC Attenuation for full 3.3V range
  analogSetAttenuation(ADC_11db);
  
  // Init Sensors
  pinMode(ACS712_SENSOR_1_PIN, INPUT);
  pinMode(ACS712_SENSOR_2_PIN, INPUT);
  pinMode(LDR_PIN, INPUT);
  dht.begin();

  // Init LCD
  lcd.init();
  lcd.backlight();
  lcd.setCursor(0,0);
  lcd.print("Energy Monitor");
  lcd.setCursor(0,1);
  lcd.print("Booting...");

  // Load Preferences
  preferences.begin("energy-audit", false);
  zeroOffset1 = preferences.getFloat("offset1", 2.5);
  zeroOffset2 = preferences.getFloat("offset2", 2.5);
  backendUrl = preferences.getString("backendUrl", "https://xenophobic-netta-cybergenii-1584fde7.koyeb.app"); // Default

  // Init WiFi (Dual Mode logic inside)
  initWiFi();

  // Init Web Server
  initWebServer();
  
  Serial.println("System Ready. Device ID: " + deviceId);
}

// --- Loop ---
void loop() {
  unsigned long now = millis();

  // Read Sensors (every 500ms)
  if (now - lastRead >= 500) {
    current1 = readACS712(ACS712_SENSOR_1_PIN, zeroOffset1);
    watts1 = current1 * DEFAULT_VOLTAGE * DEFAULT_PF;
    
    current2 = readACS712(ACS712_SENSOR_2_PIN, zeroOffset2);
    watts2 = current2 * DEFAULT_VOLTAGE * DEFAULT_PF;
    
    lightRaw = analogRead(LDR_PIN);
    lightLux = map(lightRaw, 0, 4095, 0, 2000); // Rough approximation
    
    float t = dht.readTemperature();
    float h = dht.readHumidity();
    if (!isnan(t)) temperature = t;
    if (!isnan(h)) humidity = h;

    lastRead = now;
  }

  // Send to Backend (every 5 seconds)
  if (now - lastSend >= 5000) {
    if (WiFi.status() == WL_CONNECTED && backendUrl.length() > 0) {
      sendToBackend();
    }
    lastSend = now;
  }
  
  // Update LCD (every 2 seconds)
  static unsigned long lastLcdUpdate = 0;
  static int lcdPage = 0;
  if (now - lastLcdUpdate >= 2000) {
    lastLcdUpdate = now;
    lcdPage = (lcdPage + 1) % 3;
    
    lcd.clear();
    if (lcdPage == 0) {
      lcd.setCursor(0,0);
      lcd.print("S1: " + String(watts1, 0) + "W " + String(current1, 1) + "A");
      lcd.setCursor(0,1);
      lcd.print("S2: " + String(watts2, 0) + "W " + String(current2, 1) + "A");
    } else if (lcdPage == 1) {
      lcd.setCursor(0,0);
      lcd.print("Temp: " + String(temperature, 1) + "C");
      lcd.setCursor(0,1);
      lcd.print("Hum : " + String(humidity, 0) + "%");
    } else if (lcdPage == 2) {
      lcd.setCursor(0,0);
      if (WiFi.status() == WL_CONNECTED) {
        lcd.print("IP:" + WiFi.localIP().toString());
      } else {
         lcd.print("WiFi: Connecting");
      }
      lcd.setCursor(0,1);
      lcd.print("Lux : " + String(lightLux));
    }
  }
}

// --- Sensor Logic ---
float readACS712(int pin, float zeroOffset) {
  float currentSum = 0;
  int sampleCount = 100;
  
  // RMS Calculation
  for (int i = 0; i < sampleCount; i++) {
    int adcValue = analogRead(pin);
    float voltage = (adcValue / ADC_RESOLUTION) * ADC_VOLTAGE_REF * VOLTAGE_DIVIDER_RATIO;
    float currentInst = (voltage - zeroOffset) / ACS712_SENSITIVITY;
    currentSum += currentInst * currentInst;
    delayMicroseconds(200); // Short delay
  }
  
  float rmsCurrent = sqrt(currentSum / sampleCount);
  if (rmsCurrent < 0.10) rmsCurrent = 0.0; // Increased noise filter
  
  // Debug (Throttled)
  static unsigned long lastDebug = 0;
  if (millis() - lastDebug > 5000 && pin == ACS712_SENSOR_1_PIN) {
      lastDebug = millis();
      // Print first sample's voltage as partial debug
      int raw = analogRead(pin);
      float v = (raw / ADC_RESOLUTION) * ADC_VOLTAGE_REF * VOLTAGE_DIVIDER_RATIO;
      Serial.printf("[DEBUG] Pin: %d, Raw: %d, Volts: %.2f, Offset: %.2f, RMS: %.2fA\n", pin, raw, v, zeroOffset, rmsCurrent);
  }
  
  return rmsCurrent;
}

// --- Calibration ---
void calibrateSensors() {
  Serial.println("Starting Calibration...");
  long sum1 = 0;
  long sum2 = 0;
  int samples = 1000;
  
  // Update LCD
  lcd.clear();
  lcd.setCursor(0,0);
  lcd.print("Calibrating...");
  
  for(int i=0; i<samples; i++) {
    sum1 += analogRead(ACS712_SENSOR_1_PIN);
    sum2 += analogRead(ACS712_SENSOR_2_PIN);
    delay(1);
  }
  
  float avgAdc1 = sum1 / (float)samples;
  float avgAdc2 = sum2 / (float)samples;

  Serial.printf("Avg ADC 1: %.2f\n", avgAdc1);
  Serial.printf("Avg ADC 2: %.2f\n", avgAdc2);

  zeroOffset1 = (avgAdc1 / ADC_RESOLUTION) * ADC_VOLTAGE_REF * VOLTAGE_DIVIDER_RATIO;
  zeroOffset2 = (avgAdc2 / ADC_RESOLUTION) * ADC_VOLTAGE_REF * VOLTAGE_DIVIDER_RATIO;
  
  // Sanity Check (ACS712 output should be ~2.5V or VCC/2)
  if (zeroOffset1 < 1.0 || zeroOffset1 > 4.0) {
      Serial.println("WARNING: Calibration Offset 1 out of expected range!");
      lcd.setCursor(0,1);
      lcd.print("Error: Range!");
  }

  preferences.putFloat("offset1", zeroOffset1);
  preferences.putFloat("offset2", zeroOffset2);
  
  Serial.printf("Calibrated offsets: %.2f V, %.2f V\n", zeroOffset1, zeroOffset2);
  
  if (zeroOffset1 >= 1.0 && zeroOffset1 <= 4.0) {
      lcd.setCursor(0,1);
      lcd.print("Done! " + String(zeroOffset1, 1) + "V");
  }
  delay(2000);
}

// --- Backend Communication ---
// --- Backend Communication ---
void sendToBackend() {
  if (WiFi.status() != WL_CONNECTED) return;

  WiFiClientSecure *client = new WiFiClientSecure;
  if(client) {
    client->setInsecure(); // Ignore SSL certificate validation
    HTTPClient http;
    
    String url = backendUrl + "/energy/readings";
    Serial.print("Sending to: ");
    Serial.println(url);
    
    // http.begin(*client, url); // For newer ESP32 cores
    // Or just http.begin(url) if global instace isn't needed, but explicit client is safer for HTTPS
    
    if (http.begin(*client, url)) {
        http.addHeader("Content-Type", "application/json");
        
        StaticJsonDocument<512> doc;
        doc["device_id"] = deviceId;
        doc["sensor_1"]["current_amps"] = current1;
        doc["sensor_1"]["watts"] = watts1;
        doc["sensor_1"]["voltage"] = DEFAULT_VOLTAGE;
        doc["sensor_2"]["current_amps"] = current2;
        doc["sensor_2"]["watts"] = watts2;
        doc["sensor_2"]["voltage"] = DEFAULT_VOLTAGE;
        doc["environment"]["temperature_c"] = temperature;
        doc["environment"]["humidity_percent"] = humidity;
        doc["environment"]["light_raw"] = lightRaw;
        doc["environment"]["light_lux"] = lightLux;
        
        String payload;
        serializeJson(doc, payload);
        
        int httpResponseCode = http.POST(payload);
        if (httpResponseCode > 0) {
          Serial.printf("Backend Response: %d\n", httpResponseCode);
        } else {
          Serial.printf("Backend Error: %s\n", http.errorToString(httpResponseCode).c_str());
        }
        http.end();
    } else {
      Serial.println("Unable to connect to backend");
    }
    delete client;
  } else {
    Serial.println("Unable to create client");
  }
}

// --- Web Server ---
void initWebServer() {
  server.on("/", HTTP_GET, [](AsyncWebServerRequest *request){
     String html = "<html><head><meta name='viewport' content='width=device-width, initial-scale=1'>";
     html += "<style>body{font-family:sans-serif;padding:20px;} .card{background:#f0f0f0;padding:15px;margin:10px 0;border-radius:8px;} h1{color:#333;}</style>";
     html += "<script>setInterval(() => { fetch('/api/data').then(r=>r.json()).then(d => {";
     html += "document.getElementById('c1').innerText = d.s1.amps.toFixed(2) + ' A';";
     html += "document.getElementById('w1').innerText = d.s1.watts.toFixed(1) + ' W';";
     html += "document.getElementById('c2').innerText = d.s2.amps.toFixed(2) + ' A';";
     html += "document.getElementById('w2').innerText = d.s2.watts.toFixed(1) + ' W';";
     html += "document.getElementById('env').innerText = d.env.temp + 'C / ' + d.env.hum + '%';";
     html += "}); }, 2000);</script>";
     html += "</head><body><h1>Energy Monitor</h1>";
     
     html += "<div class='card'><h2>Sensor 1</h2><p>Current: <b id='c1'>--</b></p><p>Power: <b id='w1'>--</b></p></div>";
     html += "<div class='card'><h2>Sensor 2</h2><p>Current: <b id='c2'>--</b></p><p>Power: <b id='w2'>--</b></p></div>";
     html += "<div class='card'><h2>Environment</h2><p id='env'>--</p></div>";
     
     html += "<div class='card'><h2>Actions</h2>";
     html += "<form action='/calibrate' method='post'><button>Calibrate Zero</button></form>";
     html += "<br><a href='/config'>Configure WiFi/Backend</a>";
     html += "</div></body></html>";
     request->send(200, "text/html", html);
  });

  server.on("/api/data", HTTP_GET, [](AsyncWebServerRequest *request){
    StaticJsonDocument<300> doc;
    doc["s1"]["amps"] = current1;
    doc["s1"]["watts"] = watts1;
    doc["s2"]["amps"] = current2;
    doc["s2"]["watts"] = watts2;
    doc["env"]["temp"] = temperature;
    doc["env"]["hum"] = humidity;
    String response;
    serializeJson(doc, response);
    request->send(200, "application/json", response);
  });
  
  server.on("/calibrate", HTTP_POST, [](AsyncWebServerRequest *request){
    calibrateSensors();
    request->send(200, "text/plain", "Calibration Complete");
  });
  
  server.on("/config", HTTP_GET, [](AsyncWebServerRequest *request){
    String html = "<html><body><h1>Configuration</h1><form action='/save-config' method='post'>";
    html += "Backend URL: <input type='text' name='backendUrl' value='" + backendUrl + "'><br>";
    html += "<button type='submit'>Save</button></form></body></html>";
    request->send(200, "text/html", html);
  });
  
  server.on("/save-config", HTTP_POST, [](AsyncWebServerRequest *request){
    if (request->hasParam("backendUrl", true)) {
      backendUrl = request->getParam("backendUrl", true)->value();
      preferences.putString("backendUrl", backendUrl);
    }
    request->send(200, "text/plain", "Config Saved. Rebooting...");
    delay(1000);
    ESP.restart();
  });

  server.begin();
}

// --- WiFi ---
void initWiFi() {
  Serial.println("Connecting to WiFi: cybergenii");
  WiFi.mode(WIFI_AP_STA); // Dual Mode
  
  // Try connecting to provided credentials
  WiFi.begin("MTN_4G_47649E", "9404ABD555");
  
  // Create Config AP as fallback/concurrent
  WiFi.softAP("EnergyMonitor_Setup", "energy123");
  Serial.print("AP IP: ");
  Serial.println(WiFi.softAPIP());

  // Wait for connection (non-blocking in loop, but here we just start it)
  // We will check status in loop or let it connect in background
}

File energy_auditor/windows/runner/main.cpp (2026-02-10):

#include <flutter/dart_project.h>
#include <flutter/flutter_view_controller.h>
#include <windows.h>

#include "flutter_window.h"
#include "utils.h"

int APIENTRY wWinMain(_In_ HINSTANCE instance, _In_opt_ HINSTANCE prev,
                      _In_ wchar_t *command_line, _In_ int show_command) {
  // Attach to console when present (e.g., 'flutter run') or create a
  // new console when running with a debugger.
  if (!::AttachConsole(ATTACH_PARENT_PROCESS) && ::IsDebuggerPresent()) {
    CreateAndAttachConsole();
  }

  // Initialize COM, so that it is available for use in the library and/or
  // plugins.
  ::CoInitializeEx(nullptr, COINIT_APARTMENTTHREADED);

  flutter::DartProject project(L"data");

  std::vector<std::string> command_line_arguments =
      GetCommandLineArguments();

  project.set_dart_entrypoint_arguments(std::move(command_line_arguments));

  FlutterWindow window(project);
  Win32Window::Point origin(10, 10);
  Win32Window::Size size(1280, 720);
  if (!window.Create(L"energy_auditor", origin, size)) {
    return EXIT_FAILURE;
  }
  window.SetQuitOnClose(true);

  ::MSG msg;
  while (::GetMessage(&msg, nullptr, 0, 0)) {
    ::TranslateMessage(&msg);
    ::DispatchMessage(&msg);
  }

  ::CoUninitialize();
  return EXIT_SUCCESS;
}

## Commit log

2025-12-28 Update BOM.md to remove estimated costs and clean up formatting; minor updates to other documentation files for consistency.
2025-12-29 Refactor BOM.md to improve formatting consistency by removing unnecessary trailing characters and ensuring uniformity in table headers. Added estimated cost ranges for system components.
2026-02-10 feat: Add initial energy audit circuitry design files, backups, and generated outputs.
    [energy-audit-circuitry.kicad_pcb, energy-audit-circuitry.kicad_sch]
2026-02-10 Refactor firmware by removing device data, configuration, PZEM sensor, and waste detection components, while updating the mobile app's UI, data models, API service to a remote endpoint, and adding De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
2026-02-10 feat: Standardize device ID, implement secure HTTPS communication with SSL bypass, and enhance ADC calibration and current sensing.
2026-02-10 feat: Implement voltage tracking, overhaul dashboard UI with new theme, and add environment card.
2026-02-10 feat: Implement sensor configuration management including new data models, API endpoints, Riverpod providers, and a dedicated UI in the device setup screen.
2026-02-17 gmmmmsm made again changeslll
    [energy_audit.kicad_pcb, energy_audit.kicad_sch]
